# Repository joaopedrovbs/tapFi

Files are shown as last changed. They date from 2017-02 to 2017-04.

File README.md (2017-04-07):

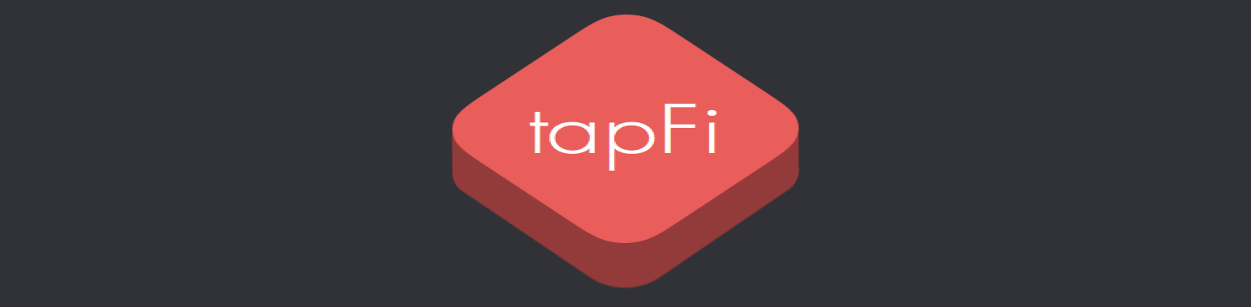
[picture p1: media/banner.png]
TapFi Banner

> The tapFi project

This contains all source files and project specs for tapFi project, including:

- tapFi BLE Api for `NodeJS`
- Cashier and Mobile WebApp written in `React` with `Electron`
- Firmware for Nordic nrf51822 ARM M0 chip
- Files for 3D Printing the case in the `.stl` format
- Parts needed for the prototypes

## Where to find

Each part is in it's own separate folder. `webapp`, `firmware`, `project` and `tapfi-api`.

## How to use it

- For flashing the `firmware` into the board visit [here](https://github.com/joaopedrovbs/tapFi/tree/master/firmware). 
- To assemble a device like the `prototype tapFi`, see [here](https://github.com/joaopedrovbs/tapFi/tree/master/hardware).
- To run the `Point of Sale created for interfacing with tapFi see [here](https://github.com/joaopedrovbs/tapFi/tree/master/webapp).

## Security

Read about security in [SECURITY.md](SECURITY.md)

## Notes
> What we found out, and Things that we should concern if continuing this project

### General

1.  At first, we thought that a "device" was our project. And we were wrong about that. 
    TapFi should not be a device, it should be a protocol instead. tapFi device is the
    usage of the protocol on a device, not a device with some specific protocol.

2.  Using NFC to "pair" to a store is a great thing. Using a CA (Certificat Authority) is
    needed to prevent unthrustable from fullfilling signatures on TapFi if an unsecure
    connection channel cannot be created from the Customer to the Merchant. NFC could be
    an alternative to "pairing", as it requires close distance to transfer data and communicate.

3.  Current [IPR](https://github.com/interledgerjs/ilp-packet/tree/f5b36b762cb87636433bb2e81c22985ab068dad6)
    is not so good for TapFi. It is not made offline payments because of it's lack in information 
    about the real amount. Read below about IPR notes.

4.  Broadcasting payments is not a bad idea. If a defined protocol for Interledger payments 
    supported "broadcast" of payments over-the-air, surrounding people could pay for a product
    prior to getting to the cashier. Showing a receipt code could act as a confirmation.
    It could be used inside Transportations (Bus/Train/Taxi) by broadcasting a nearby-payment.
    Merchants could broadcast promotions and allow customers to pay while serving or waiting to be served.

5. 

### IPR

1.  There is no way to tell if `100` is `$100.00`, `$1.00`, or `£100000000.00`.
    It means that tapFi would need to blindly sign anything without having any idea of the
    amount, and one of the basics thing that a tapFi device would have is a "spend" limit for
    un-paired payments.

2.  There should be two types of amount signing: `source` and `destination` amount. That's because
    a TapFi enabled device would require units in it's own "currency" to validate before signing, but
    If it's signing something while the merchant/device are offline, it means that the device signing
    the request would not be able to know either:

     - The correct exchange rate
     - The decimal scale used
     - The currency

    IPR should contain information about all those things in order to be safe for a customer, or a 
    flag indicating it's an `offline` payment for security reasons (that way, a ledger could track 
    security breaches better).

3.  There is no expiry on a payment. A payment made in `Muffins CO.` today, could be executed 2
    years after that. If buy `$500` today, it means that it could be discounted from your account
    much after today. That could be used to exploit exchange rates, by waiting for the "best" 
    time to fulfill payments.

### Protocol

1.  After we realized that this project was actually a use case of a protocol over BLE and not a device,
    we started a [Protocol description](#?) for it.

### Software

1.  Handling BLE connections is tricky. You need to timeout some actions otherwise you will hung 
    forever waiting for completion/response. Timing out actions is really important in all steps.

### Hardware

#### 1.  Main Board

The hardware developed for tapfi was based on the `nRF51822 Bluetooth Smart Beacon Kit` from **Nordic Semiconductor**. This board was the only one that was small enough to fit the project's small form factor. It worked without any major flaws while prototyping and had a good amount of pins for all the functionallities. The possibility of assigning any pin to peripherals like `I2C` devices made everything easier while assembling.

**Problems:** The chip was capable of handling a lof of different tasks and act like a BLE 4.1 Device, but there was a little problem with the speed which the controller performed tasks like signing and generating **Curve25519 keys**. Some operations could take as long as 1 second to get done.
  - **One Possible Solution**: Altough the board had an `ARM® Cortex™-M0` inside, it was not fast enough. The new `nRF52840` from Nordic, is a more capable and powerful microcontroller with a clock speed of 64 MHz, compared to 16 MHz on the `nRF51822`, 1MB flash and 256kB RAM, NFC capabilities, and the most important part: an **ARM® CryptoCell-310 cryptographic co-processor**, capable of speeding up, and taking the load from the main CPU on crypto related tasks. A system like tapfi would benefit a lot from this new controller, so it's a good thing to have in mind for a project continuation.
  
#### 2.  Inertial Measurement Unit - IMU

The **Invensense MPU-9250** is a very popular and powerful IMU, with it's `accelerometer`, `gyroscope` and `magnetometer` it is capable of recognising a handful of different movements (features) like `shaking`, `tapping` in all directions, `steps`, `device orientation` (on the Android Standards), and outputing `Quaternions` with fused data from it's `9 Axis`. This so called features are capable of generating `interrupts` to wake up for example another microcontroller on a single or double tap, contributing to an even more low powered system. Communicating through `I2C at 400kHz`, and updating it's feature recognition (for taps) at 200Hz there was not much to complain about this device.

**Problems:** The position of the `MPU-9250 Breakout Board` inside the prototype was quite odd, on the "top-right", this made the device a little unresponsive for some taps for example on the bottom-left where the weight of battery was located, for example.
  - **One Possible Solution**: As this was just a prototype and **PCBs** weren't made, this problem could be solved just by designing a board the size of tapfi device with the MPU IC on the middle with a well tought weight distribution.  
  
#### 3.  Device Interaction

##### 3.1  LEDs

The protype had an RGB LED to alert the user of the state of the device. This was very helpful and makes the user   interaction easier, the only thing that needs to be improved in a next version is the number of RGB LEDs that need to be on both sides, front and back, and it's position inside the case. The device could also benefit from the addition of a clear part on the case for the light to pass through.

##### 3.2  Vibration Motor

A vibrating feedback is always good on devices like tapfi, for it's low key, personal and tangible alerts. On the tapfi prototype a small Rumble Motor was used for this purpose. The best option for this case was not this kind of motor but in fact a device like Apple's Taptic Engine, making a more subtle and low power haptic feedback.

#### 4.  Firmware

Nordic has a very good documentation, and C libraries for it's devices, the problem is that for prototyping they are very difficult to build and setup, either on mac or windows. This libraries generally rely on the not so good ARM Keil IDE, and the Nordic SDK. GitHub user [Sandeedmistry](https://github.com/sandeepmistry/arduino-nRF5) made a "framework" for using Nordic boards on the much easier to use Arduino IDE. The `nRF51822 Bluetooth Smart Beacon Kit` was not included on this framework, but as all the ground work was done there was just the need to add it there for an easy to use prototyping case. This addition made the coding a lot easier and faster, but missed out some features that for a full production and deep test version would have to be programmed using Nordic SDK for a more in deep and low level use of the device. Features like ultra-low power mode, GPIO use without interference from the microcontroller, bluetooth advanced specs were not yet accessible from the framework but could be through Nordic SDK.

#### Security

1.  Using ED25519 is good to use with uController. It takes about 400ms - 1000ms to sign a given packet.

2.  It would be needed to store and retrieve root CA's on the device in order to reduce the risk of 
    exploitation. For that case the Bloom filter would be the best approach to check if a given CA
    is in our list of CA's.

3.  Rythyms works great! We didn't expected that. The implemented algorithm seems to drastically reduce
    trust on relative differences of beats. It accounts for a scaled total time, and scaled per-tap time.
    We are using a threshold of `0.7` to verify if the password is a match or not.

#### User Experience

1.  An App for tapFi would be really usefull. It could provide all the specs of a embeded tapFi device 
    with all major phone hardwares (Bluetooth Low Energy / NFC). 

2.  If developing such app, it might be possible to use the fingerprint sensor to verify the identity of the
    person. That's something we would definetly dig deeper.

## Credits

[Ivan Seidel Gomes](https://github.com/ivanseidel)

[João Pedro Vilas](https://github.com/joaopedrovbs)

[Evan Schwartz](https://github.com/emschwartz)

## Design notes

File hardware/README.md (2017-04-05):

# Hardware

At this folder you'll find all the hardware parts, what to buy and how to connect things to build a tapFi.

## Case 💼
[Download Here](https://github.com/joaopedrovbs/tapFi/tree/master/hardware/stl-files) the files to 3D Print a case.

## Parts 📲

#### The list for all the parts used in the prototype and their links can be found [here](https://docs.google.com/spreadsheets/d/1pxn552UrJLPFjxMJo8Y3OLqV407wsjz8_O9QdrBkuIY/edit?usp=sharing).

This Google Spreadsheet is for building the project from Ground Up, the tools and shipping costs to Luxembourg are also included. The parts from TagConnect are the tools that we had to use to flash the ARM microcontroller as it had a proprietary connector. 

## Fitting inside the case 🕶

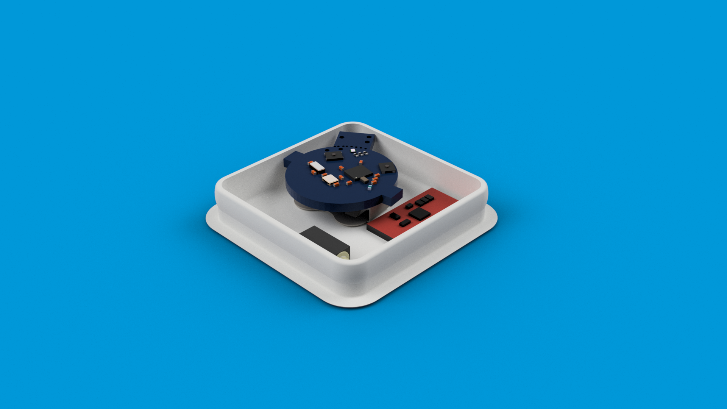
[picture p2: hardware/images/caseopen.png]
Inside Case 3d


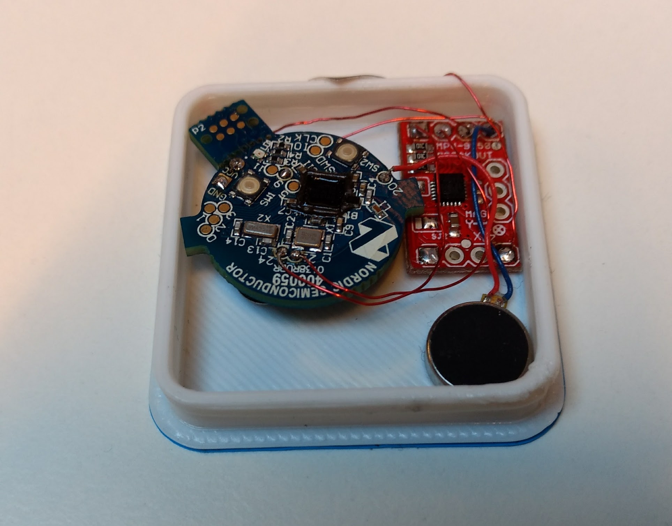
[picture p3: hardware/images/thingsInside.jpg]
Inside Real Case


Every component was hot glued to the case for better use while prototyping. 

## Connections 🔗
The connections are laid out according to the following pattern:
- `(MPU9250 Board) VDD == VCC (Beacon Board)`
- `(MPU9250 Board) GND == GND (Beacon Board)`
- `(MPU9250 Board) SDA == PIN 21 (Beacon Board)`
- `(MPU9250 Board) SCL == PIN 24 (Beacon Board)`
- `(Rumble Motor) BLUE WIRE == GND (MPU 9250 Board)`
- `(Rumble Motor) RED WIRE == PIN 20 (Beacon Board)`

## Battery Situation 🚨
As the **LOW POWER** functions from the microcontroller are not implemented the **CR1632 Battery** usually powers the system for arround `3 Hours` so it's good to remove the battery every time you finish testing.

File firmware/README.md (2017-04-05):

# How To Flash the Firmware.

The program can be Downloaded using Arduino IDE. [Download it here](https://www.arduino.cc/en/Main/Software).

Also you'll need to follow the instructions, [here](https://github.com/sandeepmistry/arduino-nRF5) to install the `Arduino Board Support` for **nRF5 Boards**. We added a PR to this Repo with the Board support we wrote. As the owner has not merged it yet. You can look for what we've changed [here](https://github.com/sandeepmistry/arduino-nRF5/pull/115).

- Inside the Arduino IDE you should copy `BLEPeripheral`, `ed25519` and `SparkFun_MPU-9250-DMP_Arduino_Library` that are on the tapFi/firmware/lib folder to your Arduino Libraries folder (Usually under `Documents/Arduino/libraries`).
- Back at the Arduino Software at: `Tools > Board` Pick **Nordic Beacon Kit (PCA20006)**. 
- On `Tools > SoftDevice` choose **S130**. 
- If you bought Everything that is on our list, the `Tools > Programmer` option should be **CMSIS-DAP**.
- As a final step Load the `TapFi.ino` file and try to compile it. 

If you installed all the libraries and followed all the steps you shoud be good to go and upload to the board.

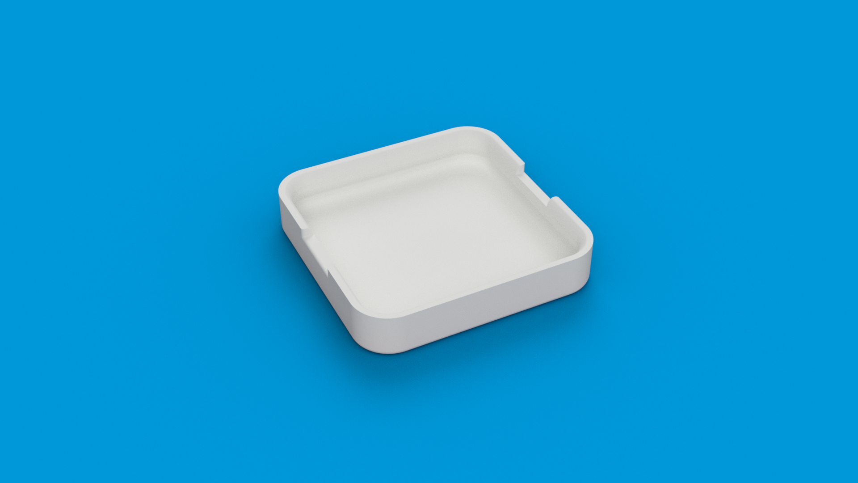
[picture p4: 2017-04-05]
hardware/images/lidOutsidePart.png

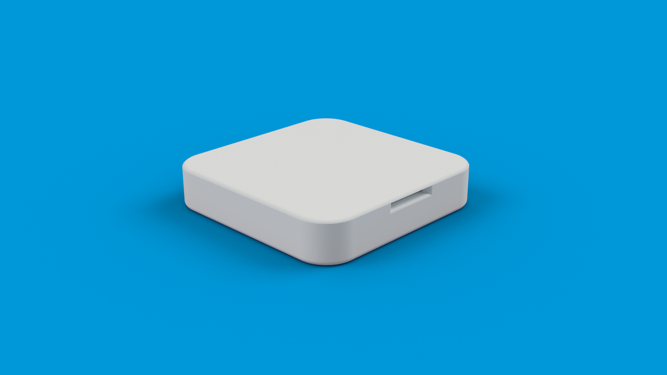
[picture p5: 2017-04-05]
hardware/images/caseRender.png

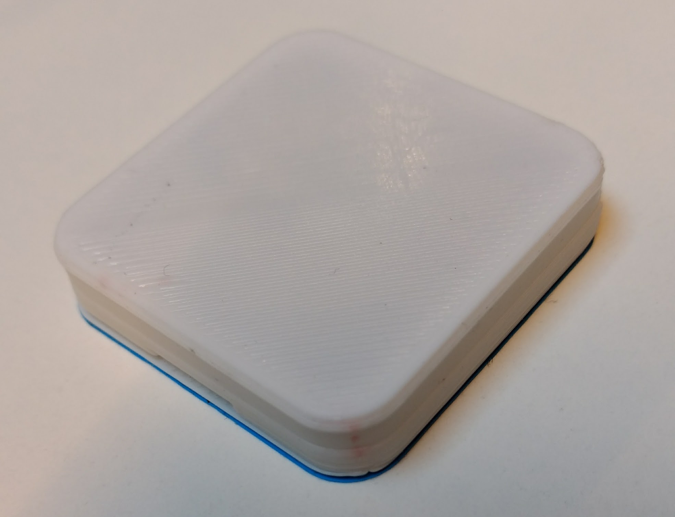
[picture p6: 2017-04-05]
hardware/images/closedWhiteCase.jpg

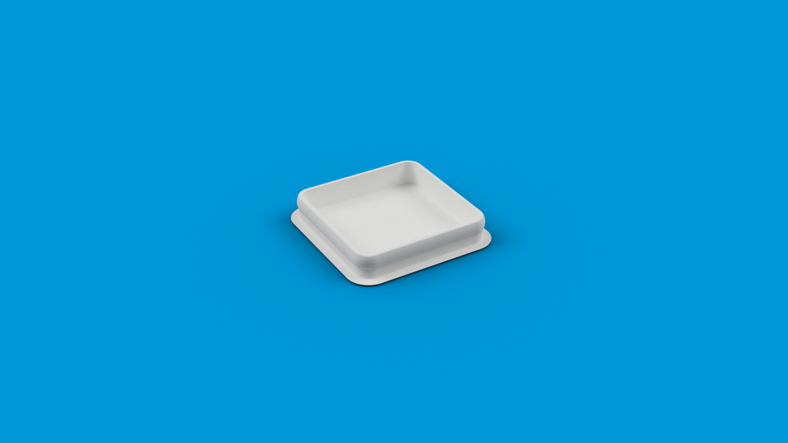
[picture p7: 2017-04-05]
hardware/images/lidInsidePart.png

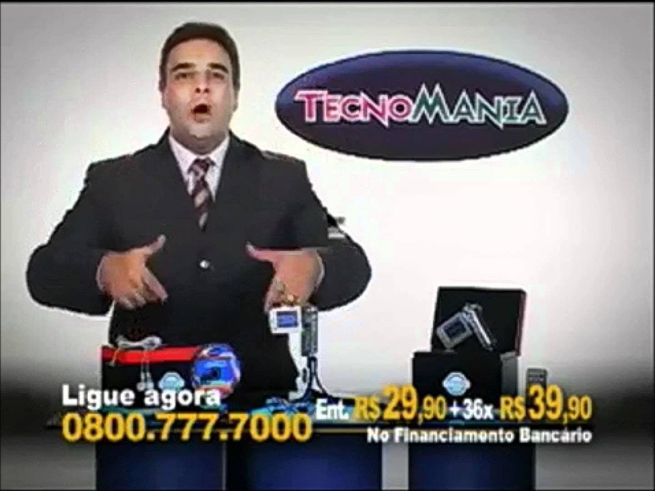
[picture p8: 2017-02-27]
webapp/barcode/maxresdefault.jpg

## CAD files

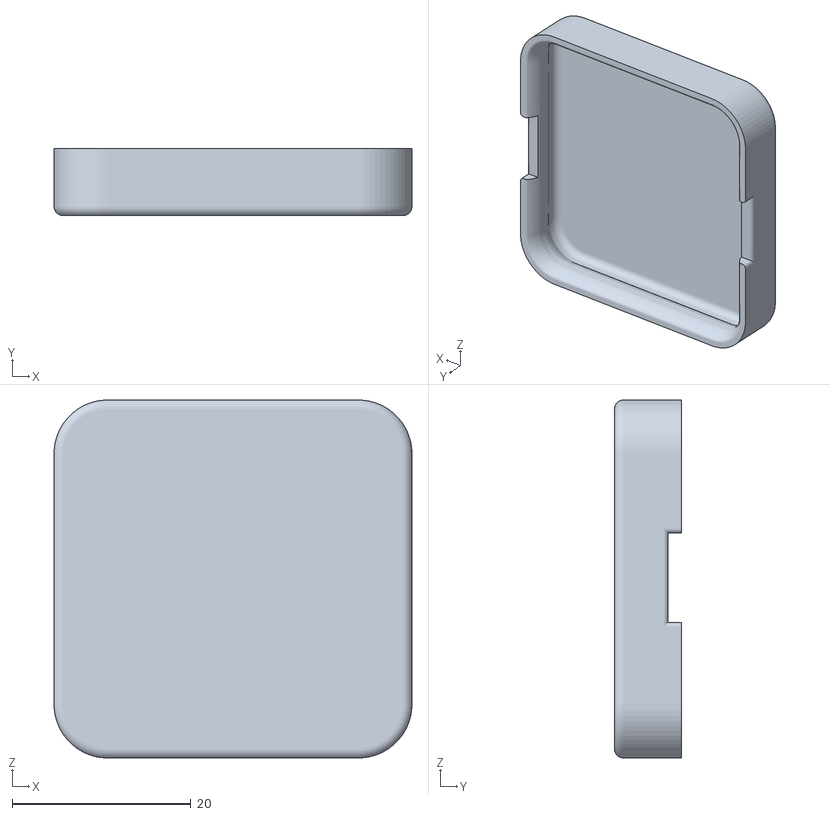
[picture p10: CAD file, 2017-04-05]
hardware/stl-files/lidOutsidePart.stl
40.0 x 7.50 x 40.0

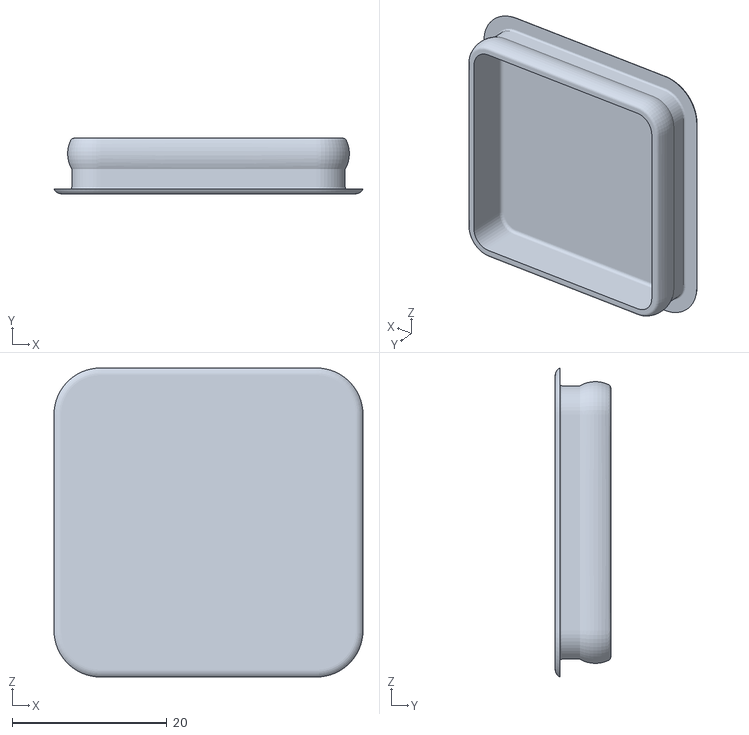
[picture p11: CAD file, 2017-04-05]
hardware/stl-files/lidInsidePart.stl
40.0 x 7.20 x 40.0

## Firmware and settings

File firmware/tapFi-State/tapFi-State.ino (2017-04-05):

//////////////////////////////////////////////////////////////////////////
////////              TapFi Payment Device Firmware               ////////
////////              João Pedro Vilas & Ivan Seidel              ////////
////////                     Luxembourg, 2017                     ////////
//////////////////////////////////////////////////////////////////////////

// Main BLE Control Library
#include <BLEPeripheral.h>
#include <LinkedList.h>
#include "MatchSequence.h"
#include "SymbolInput.h"
#include "PasswordSequence.h"
#include <SparkFunMPU9250-DMP.h>

// Stored Double Tap Timing
int doubleTap[] = {
  0,
  500
};

// Stored Password Timing 
int password[] = {
  0,             // 0, 600, 800, 1000, 1300 
  600,
  200,
  200,
  300
};

// Hardware pins of the Beacon Board
#define LED_R 16
#define LED_G 12
#define LED_B 15
#define RUMBLE 20
#define SW1 8
#define SW2 18

// Timeouts
#define CONNECTION_TIMEOUT 20000  //Timeout for connection  
#define PASSWORDENTER_TIMEOUT 5000  //Timeout for password  
#define PASSWORDTYPE_TIMEOUT 3000  //Timeout for password  
#define TAP_TIMEOUT 1200   //Timeout for Taps

// Set Ripple as Manufacturer Data
const unsigned char manufacturerData[6] = {0x52, 0x69, 0x70, 0x70, 0x6c, 0x65}; 
const char * name = "admin";
const char * domain = "john.jpvbs.com";
const char * key = "johnadmin";
const char * nAuth = "NOK";
const char * nOK = "NeM";
float maxValue = 50;

// Flags for toggling the system
bool tapfiOn = true;
bool connected = false;

// Longs for Timeout and Debouncing
unsigned long timeConnected = 0;   
unsigned long timeOn = 0;

// Create IMU Instance
MPU9250_DMP imu;

// Create peripheral instance
BLEPeripheral tapfi = BLEPeripheral();

// Create the main services
BLEService service = BLEService("1823");

// Create The characteristics
BLECharacteristic cName = BLECharacteristic("fff1", BLEBroadcast | BLERead /*| BLEWrite*/, name);
BLECharacteristic cDomain = BLECharacteristic("aaa1", BLEBroadcast | BLERead /*| BLEWrite*/, domain);
BLEFloatCharacteristic cAmount = BLEFloatCharacteristic("bbb1", BLEWrite);
BLECharacteristic cAuthorize = BLECharacteristic("ccc1", BLERead | BLENotify | BLEIndicate | BLEBroadcast, 20);
 
// Create one or more descriptors
BLEDescriptor dName = BLEDescriptor("2901", "name");
BLEDescriptor dDomain = BLEDescriptor("2901", "domain");
BLEDescriptor dAmount = BLEDescriptor("2901", "amount");
BLEDescriptor dAuthorize = BLEDescriptor("2901", "authorize");

// Instantiate Password Sequences
PasswordSequence tapPattern;
PasswordSequence tapDone;
PasswordSequence passwordSaved;
PasswordSequence passwordEntered;

// Function to control the RGB led in a simpler way
void RGB(bool r = false,bool g = false, bool b = false){
  digitalWrite(LED_R, !r);
  digitalWrite(LED_G, !g);
  digitalWrite(LED_B, !b);
}

void userAlert(short rep, short duration_ms, bool motor = true, bool r = false, bool g = false, bool b = false){
  RGB();
  for(int a = 0; a < rep; a++){
    if (motor){
      //digitalWrite(RUMBLE, HIGH);
    }
    RGB(r, g, b);
    delay(duration_ms);
    if (motor){
      //digitalWrite(RUMBLE, LOW);
    }
    RGB(r, g, b);
    delay(duration_ms);
  }
}

// Function for stopping the microcontroller and displaying errors when they occur
void haltError(int errorId, int code){
  Serial.print("Error: #");
  Serial.print(errorId);
  Serial.print(" ( ");
  Serial.print(code);
  Serial.println(" ) ");    
  while(1){
    Serial.print(".");
    digitalWrite(LED_R, !digitalRead(LED_R));    
    delay(100);
  }  
}

// Returns True if a TAP happened on the Z-Axis, either up or down
bool tapped(){
  if( imu.fifoAvailable() ){
    imu.dmpUpdateFifo();
    if( imu.tapAvailable() ){
      unsigned char tapDir = imu.getTapDir();
      switch (tapDir){
        case TAP_X_UP:
          Serial.println("TAPPED XUP");
          return true;
          break;
        case TAP_X_DOWN:
          Serial.println("TAPPED XDOWN");
          return true;
          break;
        case TAP_Y_UP:
          Serial.println("TAPPED YUP");
          return true;
          break;
        case TAP_Y_DOWN:
          Serial.println("TAPPED YDOWN");
          return true;
          break;
        case TAP_Z_UP:
          Serial.println("TAPPED ZUP");
          return true;
          break;
        case TAP_Z_DOWN:
          Serial.println("TAPPED ZDOWN");
          return true;
          break;
      }
    }
  }
  return false;
}

// Read the tap entered and store it in a password sequence
void readTap(bool debug = false){
  unsigned long lastTap = millis();

  // Always clear before re-using
  tapDone.list.clear();

  // Wait timeout && (tapDone.list.size() > 1 && millis() - lastTap < TAP_TIMEOUT)
  while( tapDone.list.size() < sizeof(doubleTap)/ sizeof(int)) {
    if (tapped()){
      // It will account for current time and create SymbolInput automatically
      tapDone.addSymbol(TAP);
      if(debug){
        Serial.print("\033[36m TAP \033[0m");
        Serial.print(tapDone.list.size());
        Serial.print(" Time: \033[31m");
        Serial.print(tapDone.list.get(tapDone.list.size() - 1).start);
        Serial.println("\033[0m");
      }
      lastTap = millis();
    }
    if(tapDone.list.size() == 1 && millis() - lastTap > TAP_TIMEOUT)
      break;
  }
}

// Check if the double tap entered is equal to the one stored returns true if ok 
bool didDoubleTap(){
  MatchParams params;                    // Configure match parameters
  params.timeScaleMax             = 1.0; // 50% speedup/speedown allowed
  params.timeScaleThrustFactor    = 0.2; //  ↑  will decrease 20% of total thrust
  params.tapDurationScaleMax      = 0.2; // 20% speedup/speedown allowed in each interval
  params.tapDurationThrustFactor  = 0.1; //  ↑  will decrease 10% of total thrust

  // Compare passwords
  float thrust = MatchSequence(&tapPattern, &tapDone, params);
  
  // Check thrust (0.7 might be something else.. need to test)
  Serial.print("Thrust: \033[34m");
  Serial.print(thrust);
  Serial.println("\033[0m");
  
  // Convert Thrust Values to Boolean
  if (thrust > 0.7) {
    return true;
  } else {
    return false;
  }
}


// Read the taps and store them in a PasswordSequence
void readPassword(bool debug = false){
  unsigned long lastTap = millis();
  
  // Always clear before re-using
  passwordEntered.list.clear();

  // Wait timeout millis() - lastTap < PASSWORD_TIMEOUT
  while(passwordEntered.list.size() < sizeof(password)/ sizeof(int) || millis() - lastTap > PASSWORDENTER_TIMEOUT){
    if (tapped()){
      // It will account for current time and create SymbolInput automatically
      passwordEntered.addSymbol(TAP);
      if(debug){
        Serial.print("\033[36m TAP \033[0m");
        Serial.print(" Time: \033[31m");
        Serial.print(passwordEntered.list.get(passwordEntered.list.size() - 1).start);
        Serial.println("\033[0m");
      }
      lastTap = millis();
    }
  if(passwordEntered.list.size() >= 1 && millis() - lastTap > PASSWORDTYPE_TIMEOUT)
      break;
  }
}

// Check the password the user entered against the recorded one, true if ok
bool didPassword(){
  MatchParams params;                    // Configure match parameters
  params.timeScaleMax             = 1.0; // 50% speedup/speedown allowed
  params.timeScaleThrustFactor    = 0.2; //  ↑  will decrease 20% of total thrust
  params.tapDurationScaleMax      = 0.4; // 20% speedup/speedown allowed in each interval
  params.tapDurationThrustFactor  = 0.1; //  ↑  will decrease 10% of total thrust
  // Compare passwords
  float thrust = MatchSequence(&passwordSaved, &passwordEntered, params);
  // Check thrust (0.7 might be something else.. need to test)
  Serial.print("Thrust 2: \033[34m");
  Serial.print(thrust);
  Serial.println("\033[0m");
  //  Converts trust to boolean
  if (thrust > 0.7) {
    return true;
  } else {
    return false;
  }
}

// Password retries and matching
bool passwordCheck(int retries){
  RGB(0,0,1);
  delay(200);
  for(int s=0; s < retries; s++){
    RGB();
    Serial.println("Try Password");
    RGB(1,1,1);
    readPassword(true);
    if(didPassword()){
      RGB();
      Serial.println("Password OK");
      userAlert(1,500,1,0,1,0);
      return true;
      break;
    }
    else{
      RGB();
      userAlert(2,500,1,1,1,0);
    }
  }

  return false;
}


void setup() {
  // Serial Initialization
  int code;
  delay(200);
  Serial.begin(115200);

  // Just for Debug
  Serial.println();
  Serial.println();
  Serial.println("Start");
  
  //Hardware Initialization
  pinMode(LED_R, OUTPUT);
  pinMode(LED_G, OUTPUT);
  pinMode(LED_B, OUTPUT);
  pinMode(RUMBLE, OUTPUT); 
  pinMode(SW1, INPUT_PULLUP);
  pinMode(SW2, INPUT_PULLUP); 
  RGB();
  
  // Setting Up BLE
  tapfi.setConnectable(true);
  tapfi.setAppearance(0x0080);
  tapfi.setTxPower(-30);
  tapfi.setLocalName("Joao Pedro"); 
  tapfi.setDeviceName("Joao Pedro");
  tapfi.setManufacturerData(manufacturerData, manufacturerData[6]);
  
  //Interval in ms
  tapfi.setAdvertisingInterval(500);
  
  //UUID for this Device
  tapfi.setAdvertisedServiceUuid("e0b76bd0-fda4-11e6-bc64-92361f002671"); 
  
  // Add attributes (services, characteristics, descriptors) to peripheral
  tapfi.addAttribute(service);
  tapfi.addAttribute(cName);
  tapfi.addAttribute(dName);
  tapfi.addAttribute(cDomain);
  tapfi.addAttribute(dDomain);
  tapfi.addAttribute(cAmount);
  tapfi.addAttribute(dAmount);
  tapfi.addAttribute(cAuthorize);
  tapfi.addAttribute(dAuthorize);

  //Starts the radio and the device
  tapfi.begin();
 
  Serial.println("TapFi Begin");
  
  // Load Saved Tap Pattern
  unsigned long totalTime = 0;
  for (unsigned int i = 0 ; i < sizeof(doubleTap) / sizeof(int) ; i++) {
    SymbolInput symb;
    
    // Increment start time
    totalTime += doubleTap[i];

    symb.type = TAP;
    symb.start = totalTime;

    tapPattern.addSymbol(symb);
  }
  Serial.print("Password Size: ");
  Serial.println(sizeof(password)/ sizeof(int));
  // Load Saved Password 
  totalTime = 0;
  for (unsigned int i = 0 ; i < sizeof(password) / sizeof(int) ; i++) {
    SymbolInput symb;
    
    // Increment start time
    totalTime += password[i];

    symb.type = TAP;
    symb.start = totalTime;

    passwordSaved.addSymbol(symb);
  }

  // Start IMU
  if (code = imu.begin())
    haltError(1, code);
  // Enables Tap Recognition at 200hz
  if (code = imu.dmpBegin(DMP_FEATURE_TAP, 200))
    haltError(2, code);

  // Tap Parameters
  unsigned short zThresh = 180;   // Set z-axis tap thresh to 100 mg/ms
  unsigned char taps = 1;         // Set minimum taps to 1
  unsigned short tapTime = 100;   // Set tap time to 100ms
  unsigned short tapMulti = 100; // Set multi-tap time to 1s
  
  // Initializes Tap with Parameters
  if(code = imu.dmpSetTap(200, 200, zThresh, taps, tapTime, tapMulti))
    haltError(3, code);

  Serial.println("Imu Begin");
} // End Setup

void loop() {
  //
  if(tapfiOn){
    RGB(1,0,0);
    Serial.println("BLE Should be OFF");
    tapfi.disconnect();
    cAuthorize.setValue(nAuth);
    tapfiOn=false;
  }
  // Read taps and record them to check
  readTap(true);
  //Check if there was a double-tap event
  if(didDoubleTap()){
    RGB();
    tapfi.poll();
    userAlert(1,500,1,0,1,0);
    Serial.println("BLE Should be ON");
    tapfiOn=true;
    timeOn=millis();
    RGB(0,1,0);
    // Awaits for connection with a certain TIMEOUT
    while(millis() - timeOn < CONNECTION_TIMEOUT){
      didConnect();
    }
  }
}

//Check for connection from Central, do value checking and exchange 
void didConnect(){
 BLECentral central = tapfi.central();
  if(central){
    timeConnected=millis();
    while (central.connected() && millis() - timeConnected < CONNECTION_TIMEOUT) { 
      if(cAmount.written()){
        Serial.print("Amount is: ");
        Serial.println(cAmount.value());
        if(maxValue - cAmount.value() >= 0 && (float) cAmount.value() > 0 && passwordCheck(3)){
          Serial.print("Key written: ");
          Serial.println(key);
          cAuthorize.setValue(key);
          cAuthorize.canNotify();
          tapfi.disconnect();
          break;
        }
        else{
          cAuthorize.setValue(nOK);
          break;
        }
      }
    }
    //tapfi.disconnect();
  }
  // else{
  //   tapfi.disconnect();
  // }
}

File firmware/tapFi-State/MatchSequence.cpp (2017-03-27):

#include <LinkedList.h>
#include "MatchSequence.h"
#include "SymbolInput.h"
#include "PasswordSequence.h"
#include <math.h>
#include <Arduino.h>

#define DEBUG false
/*
 * Given a sequence `s1`, and a test sequence `s2`, 
 * return how close s2 is to s1->
 *
 * Pass in a MatchParameters object to be used
 */
float MatchSequence(PasswordSequence *s1, PasswordSequence *s2, MatchParams params) {
  /* This is the total probability. It begins with 1.0, and will decrease with each "wrong" step */
  float totalProb = 1.0;

  /* Check for the number of each kind of event, and see if they match */
  int s1Events[SYMBOL_TYPE_NUM] = {};
  int s2Events[SYMBOL_TYPE_NUM] = {};

  for (int i = 0; i < s1->list.size(); i++) {
    int symbol = static_cast<int>(s1->list.get(i).type);
    s1Events[symbol] ++;
  }

  for (int i = 0; i < s2->list.size(); i++) {
    int symbol = static_cast<int>(s2->list.get(i).type);
    s2Events[symbol] ++;
  }

  for (int i = 0; i < SYMBOL_TYPE_NUM; i++) {
    if (s1Events[i] != s2Events[i]) {
      return ER_SYMBOLS_NOT_MATCH;
    }
  }

  /* Next, check for total time taken, and see if they are inside timeScaleMax */
  unsigned long s1Duration = s1->list.get(s1->list.size() - 1).start - s1->list.get(0).start;
  unsigned long s2Duration = s2->list.get(s2->list.size() - 1).start - s2->list.get(0).start;

  // timeScale increases if test sequence duration is greater
  float timeScale = (float) s2Duration / (float) s1Duration;
  float timeScaleAbs = fabs(1.0 - timeScale);
  if(DEBUG){
    Serial.print("timeScale | timeScaleAbs: ");
    Serial.print(timeScale);
    Serial.print(" ");
    Serial.println(timeScaleAbs);  
  }

  if (timeScaleAbs > params.timeScaleMax) {
    return ER_MAX_TIME_SCALE;
  }

  // Decrease thrust probability proportionaly to the timeScaleAbs and timeScaleThrustFactor
  totalProb -= (timeScaleAbs * params.timeScaleThrustFactor);

  /* Save TAP symbol events to a separate list */
  LinkedList<SymbolInput> s1Taps = LinkedList<SymbolInput>();
  LinkedList<SymbolInput> s2Taps = LinkedList<SymbolInput>();

  for (int i = 0; i < s1->list.size(); i ++) {
    SymbolInput symbol = s1->list.get(i);
    if(symbol.type == TAP) {
      s1Taps.add(symbol);
    }
  }

  for (int i = 0; i < s2->list.size(); i ++) {
    SymbolInput symbol = s2->list.get(i);
    if(symbol.type == TAP) {
      s2Taps.add(symbol);
    }
  }

  /* Goes through all TAP events, and decrease totalProb proportionally to it's displacement */
  unsigned long lastTap1 = 0;
  unsigned long lastTap2 = 0;
  for (int i = 0; i < s1->list.size(); i++) {
    SymbolInput tap1 = s1->list.get(i);
    SymbolInput tap2 = s2->list.get(i);

    // Compute duration between taps
    float tap1Duration = tap1.start - lastTap1;
    float tap2Duration = tap2.start - lastTap2;
    if (DEBUG){
      Serial.print("tap1Duration | tap2Duration: ");
      Serial.print(tap1Duration);
      Serial.print(" ");
      Serial.println(tap2Duration); 
    }

    // Save lastTaps
    lastTap1 = tap1.start;
    lastTap2 = tap2.start;

    // Skip first sample. It doesn't have duration yet
    if (i == 0) {
      continue;
    }

    // Get relative duration, computed with already accepted timeScale
    float durationScale = (tap2Duration / tap1Duration) * (1.0 / timeScale);
    float durationScaleAbs = fabs(1.0 - durationScale);
    if(DEBUG){
      Serial.print("durationScale | durationScaleAbs: ");
      Serial.print(durationScale);
      Serial.print(" ");
      Serial.println(durationScaleAbs);
    }


    // Check within limits
    if (durationScaleAbs > params.tapDurationScaleMax) {
      return ER_MAX_TAP_DURATION_TIME_SCALE;
    }

    // Decrease total probability proportionally
    totalProb -= (durationScaleAbs * params.tapDurationThrustFactor);
  }

  return totalProb;
}

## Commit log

2017-02-16 Add hardware folder and stl files
    Version 1 of the STL files were added to the new hardware folder, that
    will archive hardware related files
    [case v1.stl, lid v1.stl]
2017-02-16 Add lid v2
    [lid v2.stl]
2017-02-17 Add new STL file
    [lid v3.stl]
2017-03-01 Add Low Tx Power and Name
2017-03-06 Add Timeout, Buttons and LEDs
2017-03-15 Add Libs and I2C tests
2017-03-28 Fix Password recognition and loop flow
    [tapFi.ino]
2017-03-29 Fix Disconnect and BLE Toggle
    [tapFi.ino]
2017-03-30 Add Modified Libraries and Micro controller Arduino Support
2017-04-05 Add Hardware README and Assembling Instructions
    [case v1.stl, lid v1.stl, lid v2.stl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]
